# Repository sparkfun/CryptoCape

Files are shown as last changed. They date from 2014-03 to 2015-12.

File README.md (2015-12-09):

CryptoCape
==========

CryptoCape

[*CryptoCape (DEV-12773)*](https://www.sparkfun.com/products/12773)

A Cryptography Cape for the BeagleBone Black.

Repository Contents
-------------------

* **/Documentation** - PDF print of the board.
* **/Hardware** - All Eagle design files (.brd, .sch)
* **/Production** - Test bed files and production panel files

Documentation
--------------
* **[Hookup Guide](https://learn.sparkfun.com/tutorials/cryptocape-hookup-guide)** - Basic hookup guide for the CryptoCape.
* **[SparkFun Fritzing repo](https://github.com/sparkfun/Fritzing_Parts)** - Fritzing diagrams for SparkFun products.
* **[SparkFun 3D Model repo](https://github.com/sparkfun/3D_Models)** - 3D models of SparkFun products. 

License Information
-------------------

This product is _**open source**_! 

The hardware is released under [Creative Commons Share-alike 3.0](http://creativecommons.org/licenses/by-sa/3.0/).

If you have any questions or concerns on licensing, please contact techsupport@sparkfun.com.

Distributed as-is; no warranty is given.

- Your friends at SparkFun.

_This board is a collaboration with Josh Datko at Cryptotronix._

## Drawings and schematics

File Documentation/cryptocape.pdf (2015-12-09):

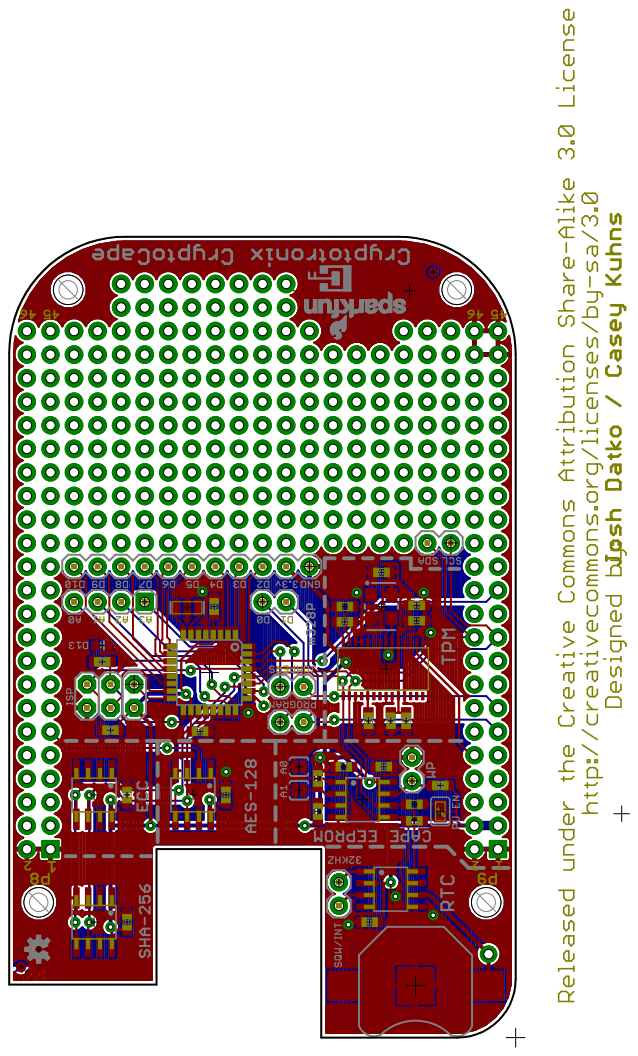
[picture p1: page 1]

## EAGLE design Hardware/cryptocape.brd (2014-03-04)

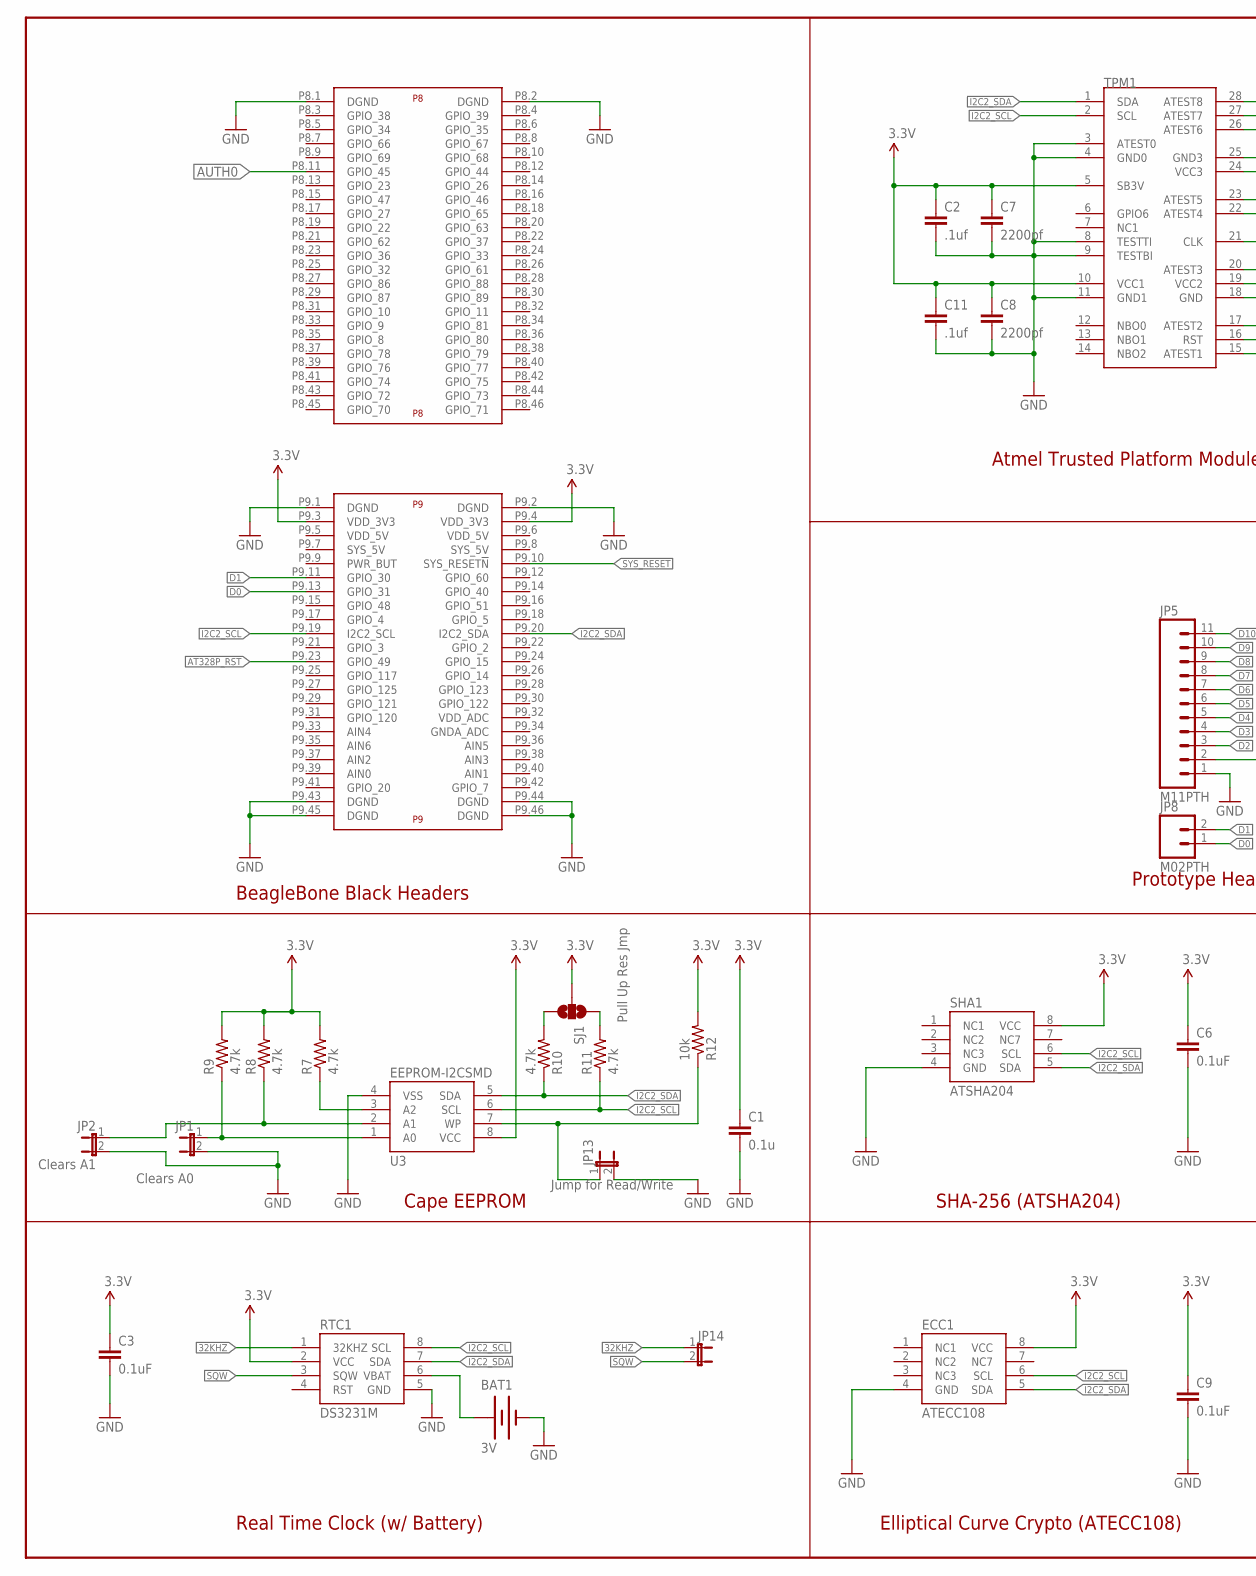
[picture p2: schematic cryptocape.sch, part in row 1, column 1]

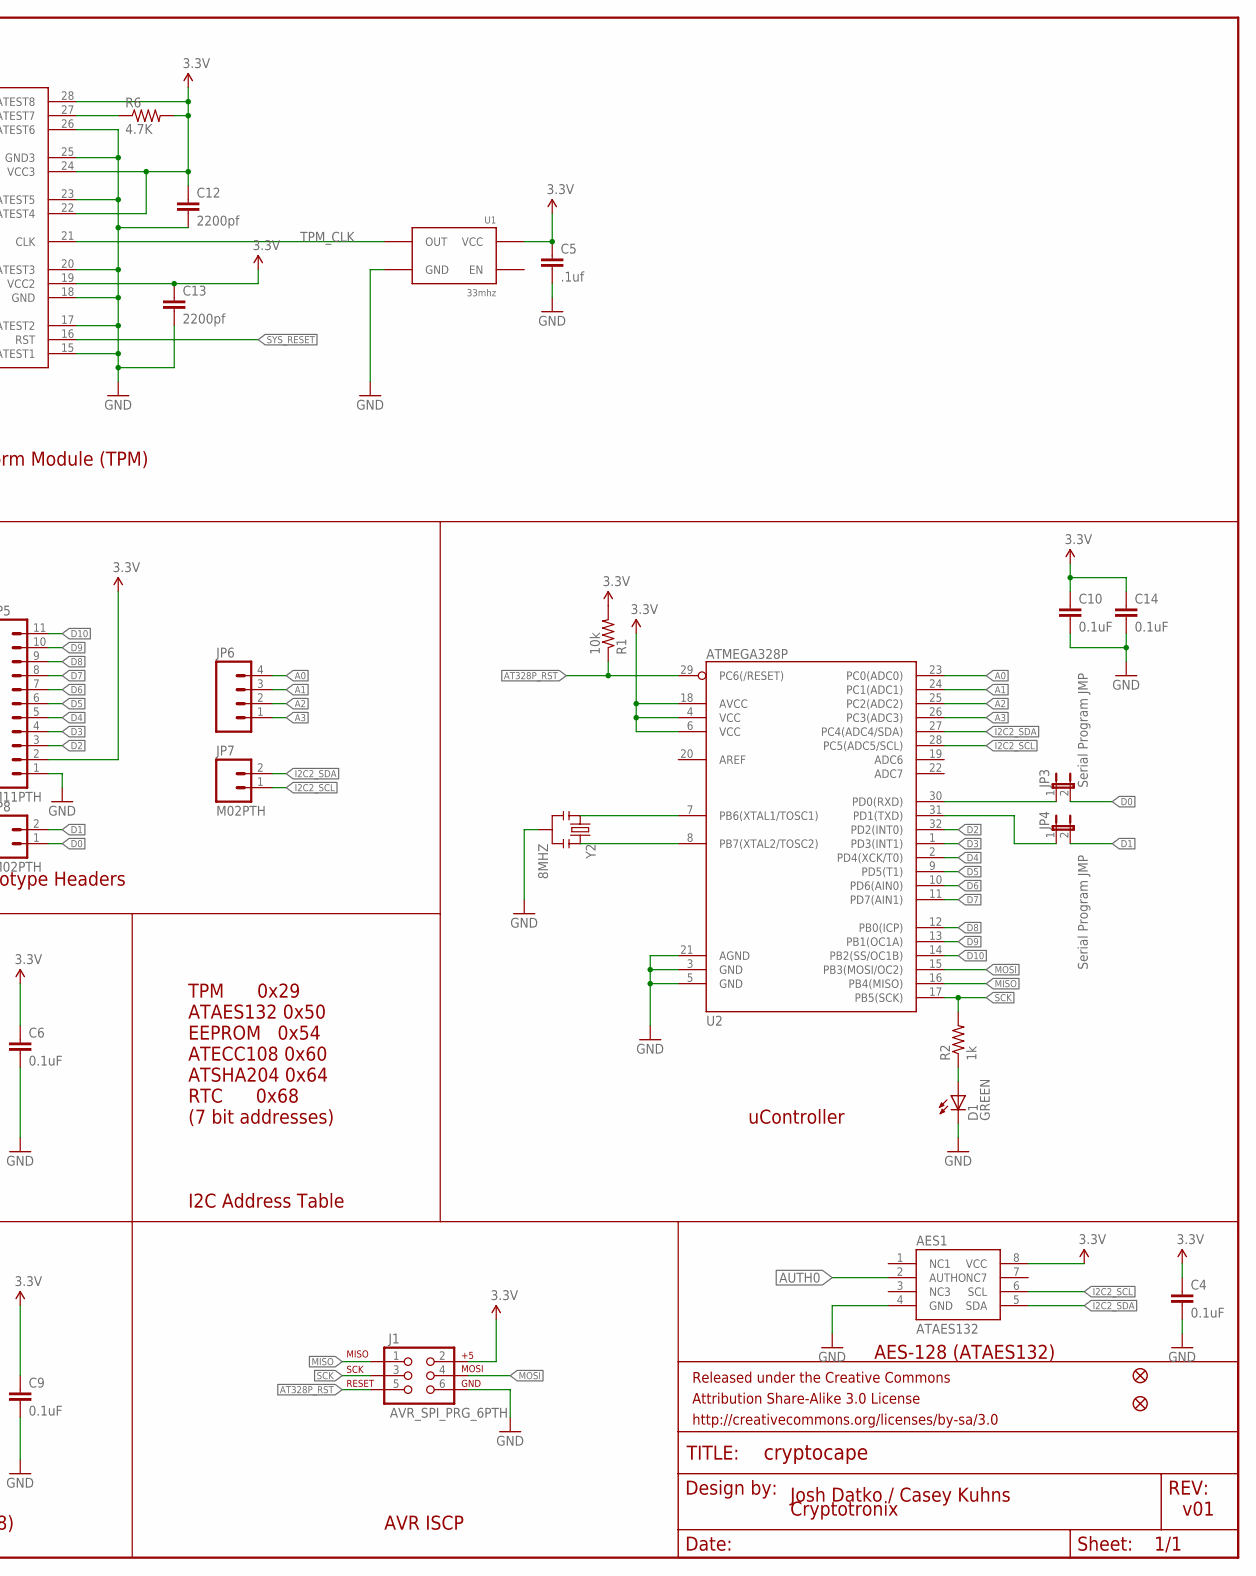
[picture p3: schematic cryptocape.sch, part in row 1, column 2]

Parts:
AES1: ATAES132; SOIC8
BAT1: 3V; BATTCON_12MM
C1: 0.1u; 0603-CAP
C2, C5, C11: .1uf; 0603-CAP
C3, C4, C6, C9, C10, C14: 0.1uF; 0603-CAP
C7, C8, C12, C13: 2200pf; 0603-CAP
D1: GREEN; LED-0603
ECC1: ATECC108; SOIC8
FID1, FID2: FIDUCIAL1X2; FIDUCIAL-1X2
FRAME1: FRAME-LEDGER; CREATIVE_COMMONS
J1: AVR_SPI_PRG_6PTH; 2X3
JP1: Clears A0; SJ_2S-NO
JP2: Clears A1; SJ_2S-NO
JP3, JP4: Serial Program JMP; 1X02
JP5: M11PTH; 1X11
JP6: M04PTH; 1X04
JP7, JP8: M02PTH; 1X02
JP13: Jump for Read/Write; 1X02
JP14: JUMPER-2PTH; 1X02
R1, R12: 10k; 0603-RES
R2: 1k; 0603-RES
R6: 4.7K; 0603
R7, R8, R9, R10, R11: 4.7k; 0603
RTC1: DS3231M; SOIC8
SHA1: ATSHA204; SOIC8
SJ1: Pull Up Res Jmp; SJ_3_PASTE1&2&3
TPM1: AT97SC3204T; TSSOP28
U1: 33mhz; CRYSTAL-OSC-SMD-5X3.2
U2: ATMEGA328P; TQFP32-08
U3: EEPROM-I2CSMD; SO08
U$2: BEAGLE_BONE_BLACK_CAPE
Y2: 8MHZ; RESONATOR-SMD

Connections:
3.3V: AES1.8 (VCC), C1.1, C2.1, C3.1, C4.1, C5.1, C6.1, C7.1, C8.1, C9.1, C10.1, C11.1, C12.1, C13.1, C14.1, ECC1.8 (VCC), J1.2, JP5.2, R1.2, R6.2, R7.2, R8.2, R9.2, R12.2, RTC1.2 (VCC), SHA1.8 (VCC), SJ1.2, TPM1.5 (SB3V), TPM1.10 (VCC1), TPM1.19 (VCC2), TPM1.22 (ATEST4), TPM1.24 (VCC3), TPM1.28 (ATEST8), U1.4 (VCC), U2.4 (VCC), U2.6 (VCC), U2.18 (AVCC), U3.8 (VCC), U$2.P9.3 (VDD_3V3), U$2.P9.4 (VDD_3V3)
32KHZ: JP14.1, RTC1.1 (32KHZ)
A0: JP6.4, U2.23 (PC0(ADC0))
A1: JP6.3, U2.24 (PC1(ADC1))
A2: JP6.2, U2.25 (PC2(ADC2))
A3: JP6.1, U2.26 (PC3(ADC3))
AT328P_RST: J1.5, R1.1, U2.29 (PC6(/RESET)), U$2.P9.23 (GPIO_49)
AUTH0: AES1.2 (AUTHO), U$2.P8.11 (GPIO_45)
D0: JP3.2, JP8.1, U$2.P9.13 (GPIO_31)
D0': JP3.1, U2.30 (PD0(RXD))
D1: JP4.2, JP8.2, U$2.P9.11 (GPIO_30)
D1': JP4.1, U2.31 (PD1(TXD))
D2: JP5.3, U2.32 (PD2(INT0))
D3: JP5.4, U2.1 (PD3(INT1))
D4: JP5.5, U2.2 (PD4(XCK/T0))
D5: JP5.6, U2.9 (PD5(T1))
D6: JP5.7, U2.10 (PD6(AIN0))
D7: JP5.8, U2.11 (PD7(AIN1))
D8: JP5.9, U2.12 (PB0(ICP))
D9: JP5.10, U2.13 (PB1(OC1A))
D10: JP5.11, U2.14 (PB2(SS/OC1B))
GND: AES1.4 (GND), BAT1.GND (-), C1.2, C2.2, C3.2, C4.2, C5.2, C6.2, C7.2, C8.2, C9.2, C10.2, C11.2, C12.2, C13.2, C14.2, D1.C, ECC1.4 (GND), J1.6, JP1.2, JP2.2, JP5.1, JP13.2, RTC1.5 (GND), SHA1.4 (GND), TPM1.3 (ATEST0), TPM1.4 (GND0), TPM1.8 (TESTTI), TPM1.9 (TESTBI), TPM1.11 (GND1), TPM1.15 (ATEST1), TPM1.17 (ATEST2), TPM1.18 (GND), TPM1.20 (ATEST3), TPM1.23 (ATEST5), TPM1.25 (GND3), TPM1.26 (ATEST6), U1.2 (GND), U2.3 (GND), U2.5 (GND), U2.21 (AGND), U3.4 (VSS), U$2.P8.1 (DGND), U$2.P8.2 (DGND), U$2.P9.1 (DGND), U$2.P9.2 (DGND), U$2.P9.43 (DGND), U$2.P9.44 (DGND), U$2.P9.45 (DGND), U$2.P9.46 (DGND), Y2.2
I2C2_SCL: AES1.6 (SCL), ECC1.6 (SCL), JP7.1, R11.1, RTC1.8 (SCL), SHA1.6 (SCL), TPM1.2 (SCL), U2.28 (PC5(ADC5/SCL)), U3.6 (SCL), U$2.P9.19 (I2C2_SCL)
I2C2_SDA: AES1.5 (SDA), ECC1.5 (SDA), JP7.2, R10.1, RTC1.7 (SDA), SHA1.5 (SDA), TPM1.1 (SDA), U2.27 (PC4(ADC4/SDA)), U3.5 (SDA), U$2.P9.20 (I2C2_SDA)
MISO: J1.1, U2.16 (PB4(MISO))
MOSI: J1.4, U2.15 (PB3(MOSI/OC2))
unnamed: JP13.1, R12.1, U3.7 (WP)
unnamed: U2.7 (PB6(XTAL1/TOSC1)), Y2.1
unnamed: U2.8 (PB7(XTAL2/TOSC2)), Y2.3
unnamed: D1.A, R2.1
unnamed: R7.1, U3.3 (A2)
unnamed: R6.1, TPM1.27 (ATEST7)
unnamed: JP2.1, R8.1, U3.2 (A1)
unnamed: JP1.1, R9.1, U3.1 (A0)
unnamed: R10.2, SJ1.3
unnamed: R11.2, SJ1.1
SCK: J1.3, R2.2, U2.17 (PB5(SCK))
SQW: JP14.2, RTC1.3 (SQW)
SYS_RESET: TPM1.16 (RST), U$2.P9.10 (SYS_RESET!N)
TPM_CLK: TPM1.21 (CLK), U1.3 (OUT)
VBAT: BAT1.PWR@1 (+), RTC1.6 (VBAT)

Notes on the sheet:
Cryptotronix
BeagleBone Black Headers
Cape EEPROM
Real Time Clock (w/ Battery)
Atmel Trusted Platform Module (TPM)
Elliptical Curve Crypto (ATECC108)
AVR ISCP
uController
SHA-256 (ATSHA204)
Prototype Headers
I2C Address Table
TPM 0x29 ATAES132 0x50 EEPROM 0x54 ATECC108 0x60 ATSHA204 0x64 RTC 0x68 (7 bit addresses)
AES-128 (ATAES132)
Josh Datko / Casey Kuhns
v01

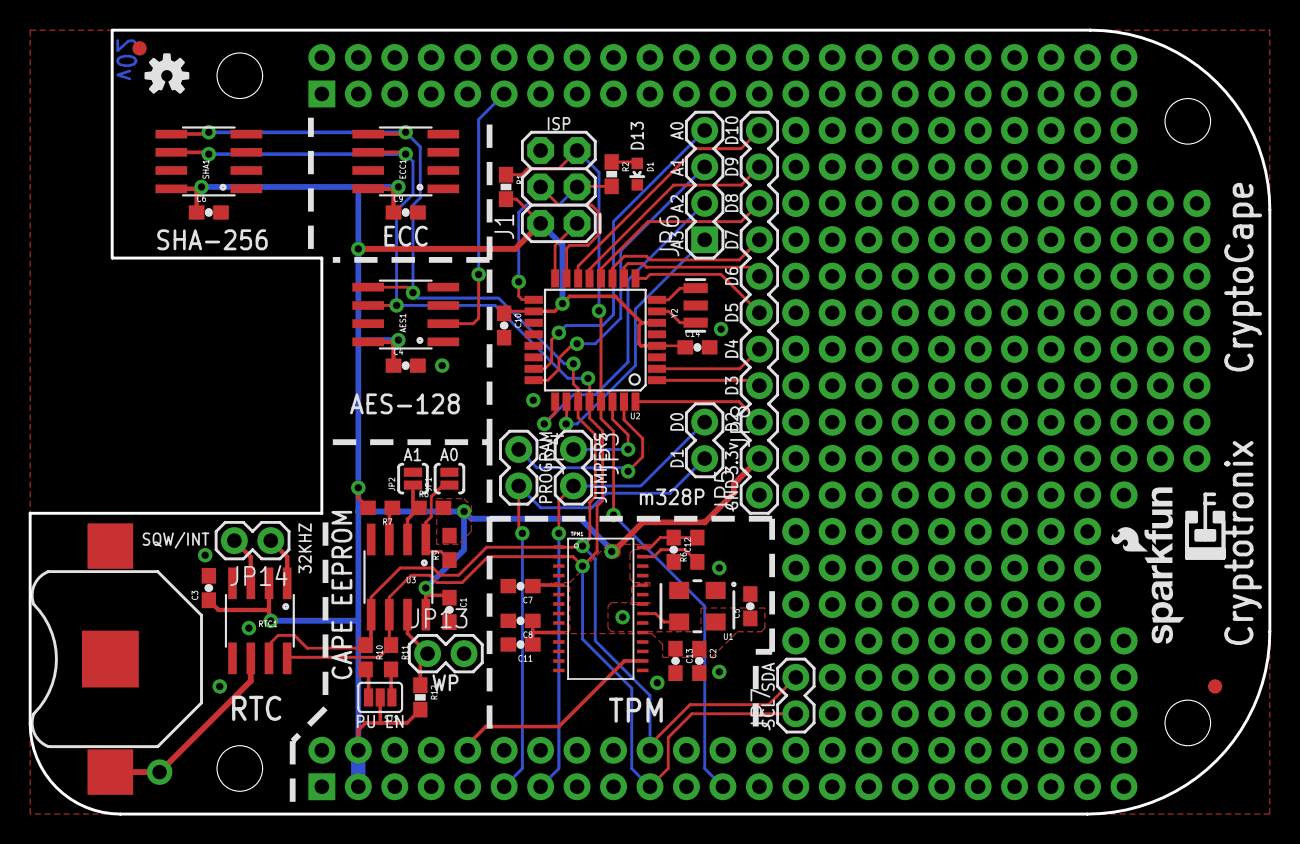
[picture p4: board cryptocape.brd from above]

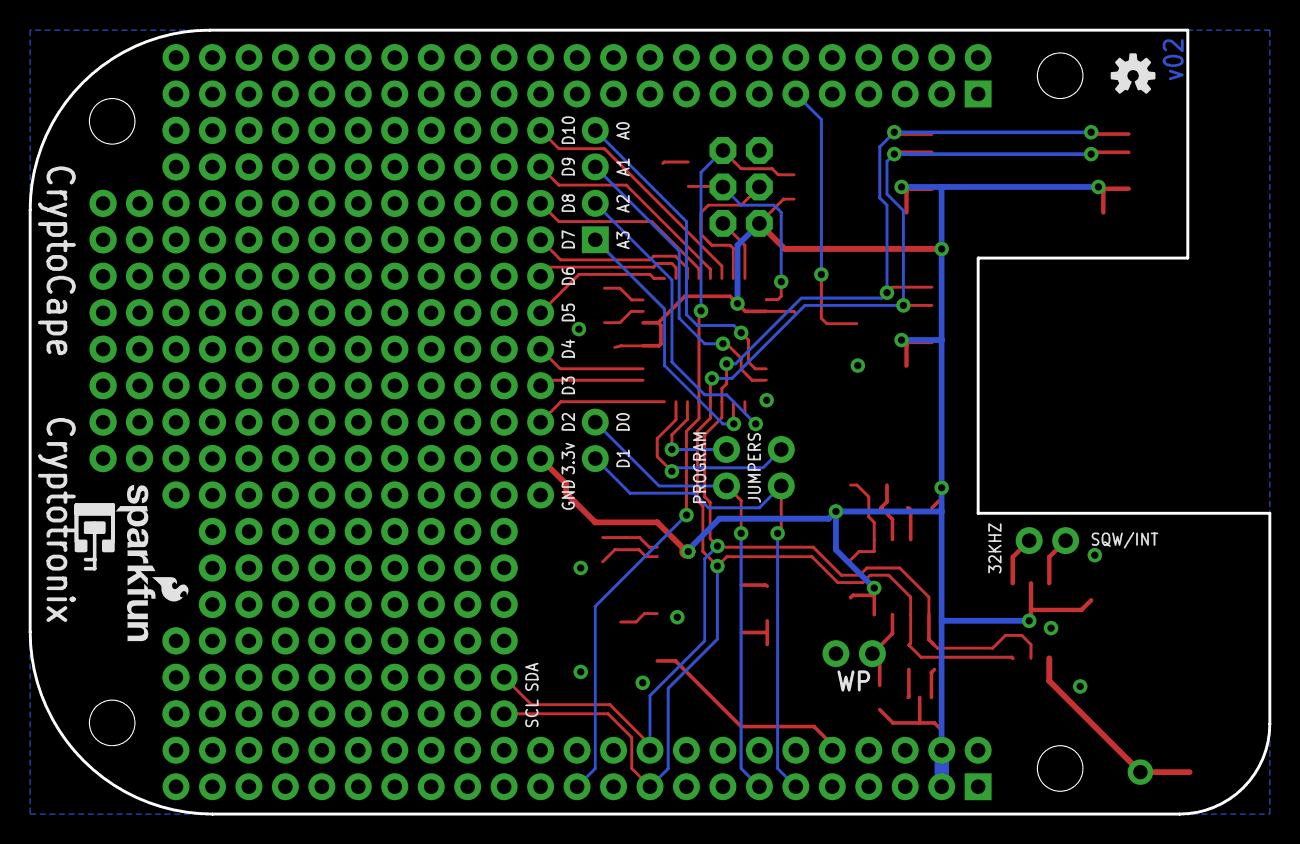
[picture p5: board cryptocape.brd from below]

Board: 2 copper layers, 86.4 x 54.6 mm, 54 parts (2 on the bottom side), 41 nets.

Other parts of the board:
U$3, U$6: OSHW-LOGO-S
U$4, U$5: SFE_LOGO_NAME_FLAME_.1

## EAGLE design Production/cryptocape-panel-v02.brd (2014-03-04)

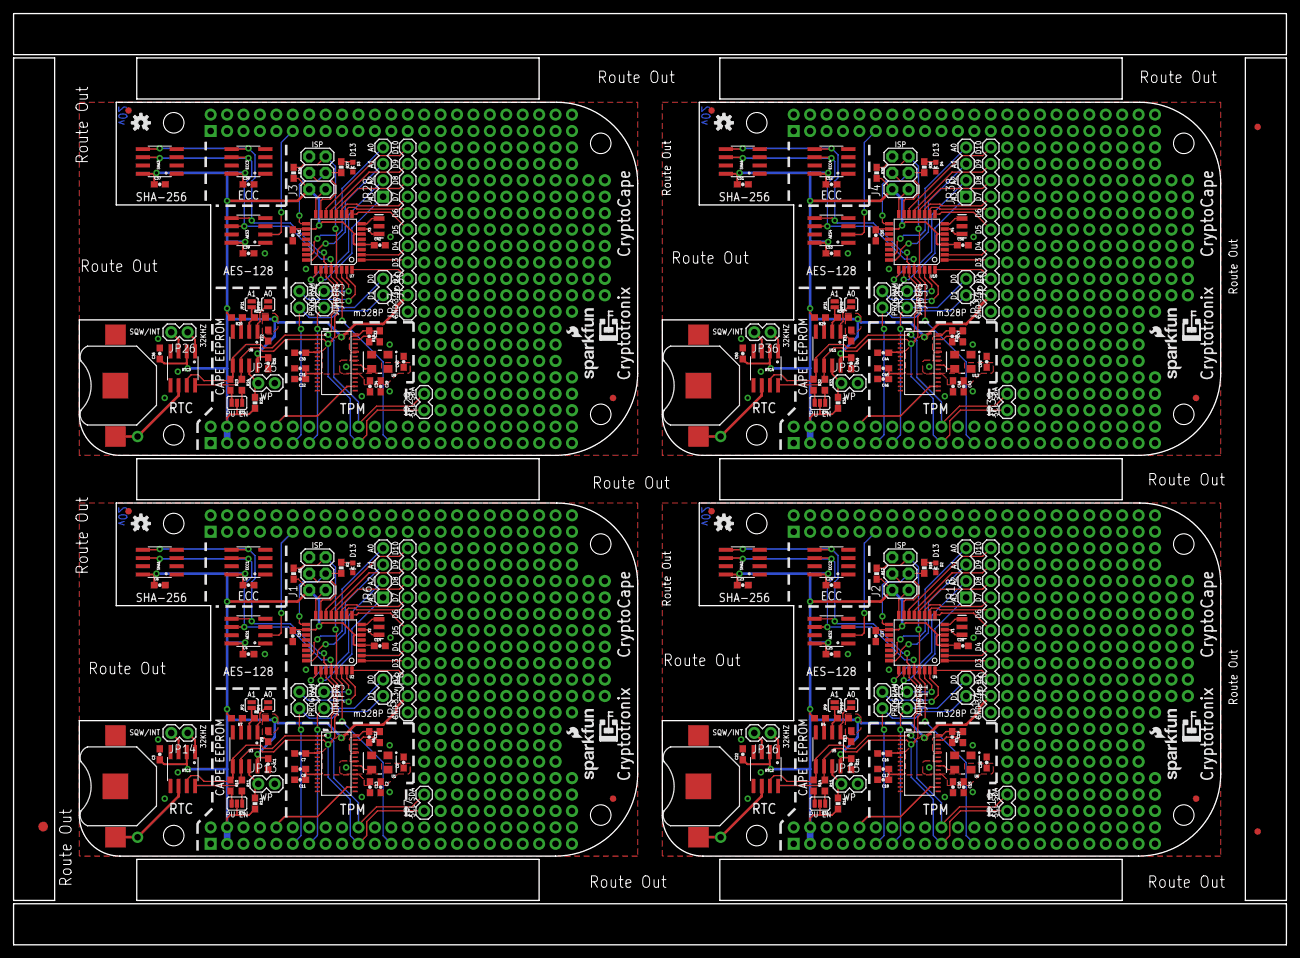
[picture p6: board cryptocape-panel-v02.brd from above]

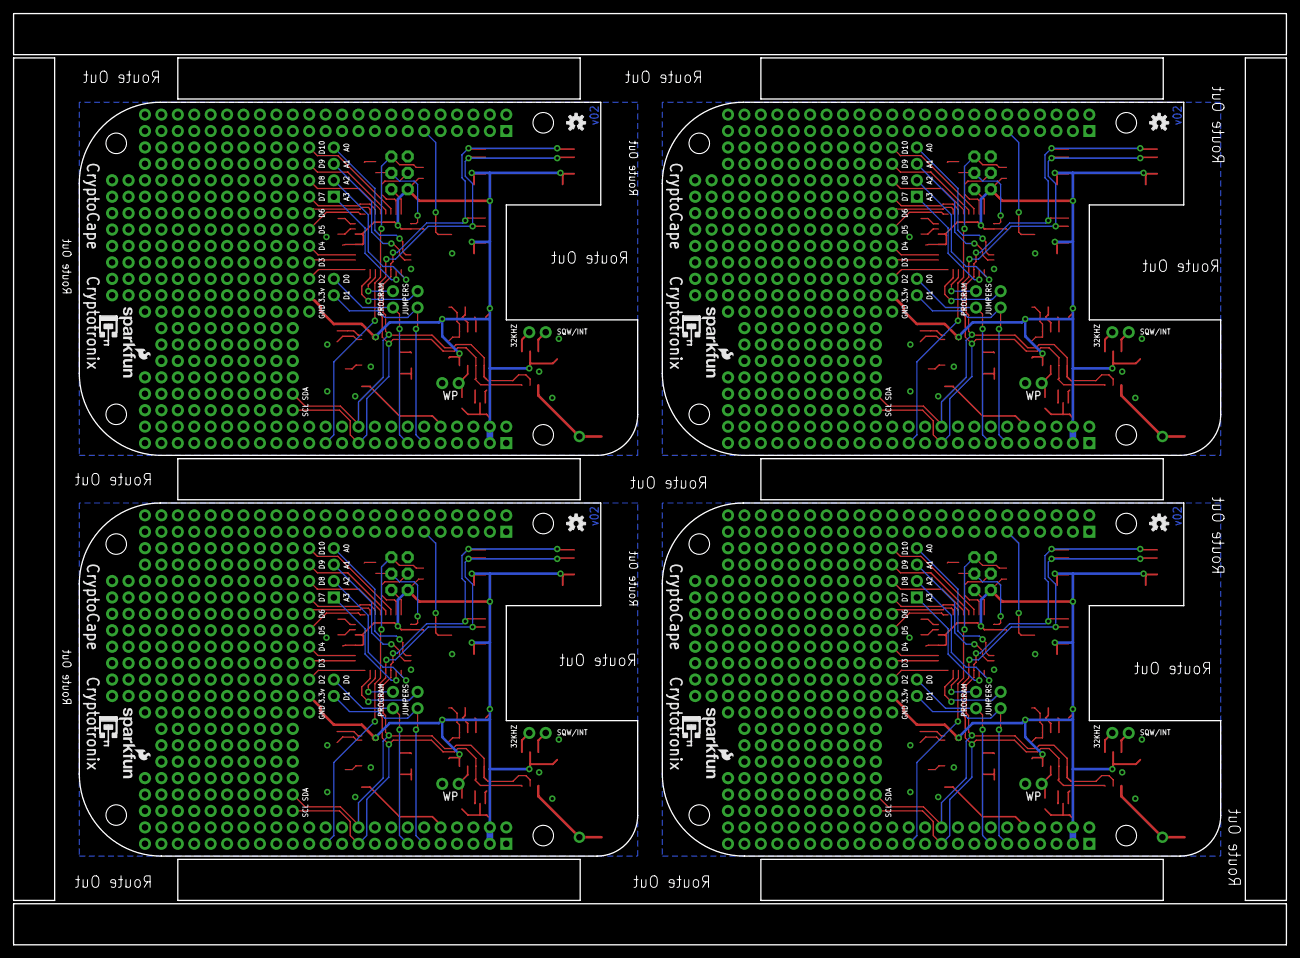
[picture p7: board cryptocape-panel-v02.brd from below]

Board: 2 copper layers, 196.8 x 144.0 mm, 215 parts (8 on the bottom side), 164 nets.

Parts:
AES1, AES2, AES3, AES4: ATAES132; SOIC8
BAT1, BAT2, BAT3, BAT4: 3V; BATTCON_12MM
C1, C21, C35, C49: 0.1u; 0603-CAP
C2, C5, C11, C15, C18, C26, C29, C32, C40, C43, C46, C54: .1uf; 0603-CAP
C3, C4, C6, C9, C10, C14, C22, C23, C24, C25, C27, C28, C36, C37, C38, C39, C41, C42, C50, C51, C52, C53, C55, C56: 0.1uF; 0603-CAP
C7, C8, C12, C13, C16, C17, C19, C20, C30, C31, C33, C34, C44, C45, C47, C48: 2200pf; 0603-CAP
D1, D2, D3, D4: GREEN; LED-0603
E$1: FIDUCIAL-1.5X3
E$12, E$14: FIDUCIAL-1X2
ECC1, ECC2, ECC3, ECC4: ATECC108; SOIC8
FID1, FID2, FID3, FID4, FID5, FID6, FID7, FID8: FIDUCIAL1X2; FIDUCIAL-1X2
J1, J2, J3, J4: AVR_SPI_PRG_6PTH; 2X3
JP1, JP10, JP22, JP32: Clears A0; SJ_2S-NO
JP2, JP9, JP21, JP31: Clears A1; SJ_2S-NO
JP3, JP4, JP11, JP12, JP23, JP24, JP33, JP34: Serial Program JMP; 1X02
JP5, JP17, JP27, JP37: M11PTH; 1X11
JP6, JP18, JP28, JP38: 1X04
JP7, JP8, JP19, JP20, JP29, JP30, JP39, JP40: M02PTH; 1X02
JP13, JP15, JP25, JP35: Jump for Read/Write; 1X02
JP14, JP16, JP26, JP36: 1X02
R1, R12, R16, R17, R25, R26, R34, R35: 10k; 0603-RES
R2, R18, R27, R36: 1k; 0603-RES
R3, R6, R19, R28: 4.7K; 0603
R4, R5, R7, R8, R9, R10, R11, R13, R14, R15, R20, R21, R22, R23, R24, R29, R30, R31, R32, R33: 4.7k; 0603
RTC1, RTC2, RTC3, RTC4: DS3231M; SOIC8
SHA1, SHA2, SHA3, SHA4: ATSHA204; SOIC8
SJ1, SJ2, SJ3, SJ4: Pull Up Res Jmp; SJ_3_PASTE1&2&3
TPM1, TPM2, TPM3, TPM4: AT97SC3204T; TSSOP28
U1, U6, U9, U12: 33mhz; CRYSTAL-OSC-SMD-5X3.2
U2, U4, U7, U10: ATMEGA328P; TQFP32-08
U3, U5, U8, U11: EEPROM-I2CSMD; SO08
U$1, U$2, U$11, U$16: BEAGLE_BONE_BLACK_CAPE
U$3, U$6, U$7, U$10, U$12, U$15, U$17, U$20: OSHW-LOGO-S
U$4, U$5, U$8, U$9, U$13, U$14, U$18, U$19: SFE_LOGO_NAME_FLAME_.1
Y1, Y2, Y3, Y4: 8MHZ; RESONATOR-SMD

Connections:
3.3V: AES1.8, C1.1, C2.1, C3.1, C4.1, C5.1, C6.1, C7.1, C8.1, C9.1, C10.1, C11.1, C12.1, C13.1, C14.1, ECC1.8, J1.2, JP5.2, R1.2, R6.2, R7.2, R8.2, R9.2, R12.2, RTC1.2, SHA1.8, SJ1.2, TPM1.5, TPM1.10, TPM1.19, TPM1.22, TPM1.24, TPM1.28, U1.4, U2.4, U2.6, U2.18, U3.8, U$2.P9.3, U$2.P9.4
3.3V1: AES2.8, C15.1, C16.1, C17.1, C18.1, C19.1, C20.1, C21.1, C22.1, C23.1, C24.1, C25.1, C26.1, C27.1, C28.1, ECC2.8, J2.2, JP17.2, R3.2, R4.2, R5.2, R13.2, R16.2, R17.2, RTC2.2, SHA2.8, SJ2.2, TPM2.5, TPM2.10, TPM2.19, TPM2.22, TPM2.24, TPM2.28, U4.4, U4.6, U4.18, U5.8, U6.4, U$1.P9.3, U$1.P9.4
3.3V2: AES3.8, C29.1, C30.1, C31.1, C32.1, C33.1, C34.1, C35.1, C36.1, C37.1, C38.1, C39.1, C40.1, C41.1, C42.1, ECC3.8, J3.2, JP27.2, R19.2, R20.2, R21.2, R22.2, R25.2, R26.2, RTC3.2, SHA3.8, SJ3.2, TPM3.5, TPM3.10, TPM3.19, TPM3.22, TPM3.24, TPM3.28, U7.4, U7.6, U7.18, U8.8, U9.4, U$11.P9.3, U$11.P9.4
3.3V3: AES4.8, C43.1, C44.1, C45.1, C46.1, C47.1, C48.1, C49.1, C50.1, C51.1, C52.1, C53.1, C54.1, C55.1, C56.1, ECC4.8, J4.2, JP37.2, R28.2, R29.2, R30.2, R31.2, R34.2, R35.2, RTC4.2, SHA4.8, SJ4.2, TPM4.5, TPM4.10, TPM4.19, TPM4.22, TPM4.24, TPM4.28, U10.4, U10.6, U10.18, U11.8, U12.4, U$16.P9.3, U$16.P9.4
32KHZ: JP14.1, RTC1.1
32KHZ1: JP16.1, RTC2.1
32KHZ2: JP26.1, RTC3.1
32KHZ3: JP36.1, RTC4.1
A0: JP6.4, U2.23
A1: JP6.3, U2.24
A2: JP6.2, U2.25
A3: JP6.1, U2.26
A4: JP18.3, U4.24
A5: JP18.2, U4.25
A6: JP18.1, U4.26
A7: JP18.4, U4.23
A8: JP28.3, U7.24
A9: JP28.2, U7.25
A10: JP28.1, U7.26
A11: JP28.4, U7.23
A12: JP38.3, U10.24
A13: JP38.2, U10.25
A14: JP38.1, U10.26
A15: JP38.4, U10.23
AT328P_RST: J1.5, R1.1, U2.29, U$2.P9.23
AT328P_RST1: J2.5, R17.1, U4.29, U$1.P9.23
AT328P_RST2: J3.5, R26.1, U7.29, U$11.P9.23
AT328P_RST3: J4.5, R35.1, U10.29, U$16.P9.23
AUTH0: AES1.2, U$2.P8.11
AUTH1: AES2.2, U$1.P8.11
AUTH2: AES3.2, U$11.P8.11
AUTH3: AES4.2, U$16.P8.11
D0: JP3.2, JP8.1, U$2.P9.13
D0': JP3.1, U2.30
D0'1: JP11.1, U4.30
D0'2: JP23.1, U7.30
D0'3: JP33.1, U10.30
D1: JP4.2, JP8.2, U$2.P9.11
D1': JP4.1, U2.31
D1'1: JP12.1, U4.31
D1'2: JP24.1, U7.31
D1'3: JP34.1, U10.31
D2: JP5.3, U2.32
D3: JP5.4, U2.1
D4: JP5.5, U2.2
D5: JP5.6, U2.9
D6: JP5.7, U2.10
D7: JP5.8, U2.11
D8: JP5.9, U2.12
D9: JP5.10, U2.13
D10: JP5.11, U2.14
D11: JP11.2, JP20.1, U$1.P9.13
D12: JP12.2, JP20.2, U$1.P9.11
D13: JP17.3, U4.32
D14: JP17.4, U4.1
D15: JP17.5, U4.2
D16: JP17.6, U4.9
D17: JP17.7, U4.10
D18: JP17.8, U4.11
D19: JP17.9, U4.12
D20: JP17.10, U4.13
D21: JP17.11, U4.14
D22: JP23.2, JP30.1, U$11.P9.13
D23: JP24.2, JP30.2, U$11.P9.11
D24: JP27.3, U7.32
D25: JP27.4, U7.1
D26: JP27.5, U7.2
D27: JP27.6, U7.9
D28: JP27.7, U7.10
D29: JP27.8, U7.11
D30: JP27.9, U7.12
D31: JP27.10, U7.13
D32: JP27.11, U7.14
D33: JP33.2, JP40.1, U$16.P9.13
D34: JP34.2, JP40.2, U$16.P9.11
D35: JP37.3, U10.32
D36: JP37.4, U10.1
D37: JP37.5, U10.2
D38: JP37.6, U10.9
D39: JP37.7, U10.10
D40: JP37.8, U10.11
D41: JP37.9, U10.12
D42: JP37.10, U10.13
D43: JP37.11, U10.14
GND: AES1.4, BAT1.GND, C1.2, C2.2, C3.2, C4.2, C5.2, C6.2, C7.2, C8.2, C9.2, C10.2, C11.2, C12.2, C13.2, C14.2, D1.C, ECC1.4, J1.6, JP1.2, JP2.2, JP5.1, JP13.2, RTC1.5, SHA1.4, TPM1.3, TPM1.4, TPM1.8, TPM1.9, TPM1.11, TPM1.15, TPM1.17, TPM1.18, TPM1.20, TPM1.23, TPM1.25, TPM1.26, U1.2, U2.3, U2.5, U2.21, U3.4, U$2.P8.1, U$2.P8.2, U$2.P9.1, U$2.P9.2, U$2.P9.43, U$2.P9.44, U$2.P9.45, U$2.P9.46, Y2.2
GND1: AES2.4, BAT2.GND, C15.2, C16.2, C17.2, C18.2, C19.2, C20.2, C21.2, C22.2, C23.2, C24.2, C25.2, C26.2, C27.2, C28.2, D2.C, ECC2.4, J2.6, JP9.2, JP10.2, JP15.2, JP17.1, RTC2.5, SHA2.4, TPM2.3, TPM2.4, TPM2.8, TPM2.9, TPM2.11, TPM2.15, TPM2.17, TPM2.18, TPM2.20, TPM2.23, TPM2.25, TPM2.26, U4.3, U4.5, U4.21, U5.4, U6.2, U$1.P8.1, U$1.P8.2, U$1.P9.1, U$1.P9.2, U$1.P9.43, U$1.P9.44, U$1.P9.45, U$1.P9.46, Y1.2
GND2: AES3.4, BAT3.GND, C29.2, C30.2, C31.2, C32.2, C33.2, C34.2, C35.2, C36.2, C37.2, C38.2, C39.2, C40.2, C41.2, C42.2, D3.C, ECC3.4, J3.6, JP21.2, JP22.2, JP25.2, JP27.1, RTC3.5, SHA3.4, TPM3.3, TPM3.4, TPM3.8, TPM3.9, TPM3.11, TPM3.15, TPM3.17, TPM3.18, TPM3.20, TPM3.23, TPM3.25, TPM3.26, U7.3, U7.5, U7.21, U8.4, U9.2, U$11.P8.1, U$11.P8.2, U$11.P9.1, U$11.P9.2, U$11.P9.43, U$11.P9.44, U$11.P9.45, U$11.P9.46, Y3.2
GND3: AES4.4, BAT4.GND, C43.2, C44.2, C45.2, C46.2, C47.2, C48.2, C49.2, C50.2, C51.2, C52.2, C53.2, C54.2, C55.2, C56.2, D4.C, ECC4.4, J4.6, JP31.2, JP32.2, JP35.2, JP37.1, RTC4.5, SHA4.4, TPM4.3, TPM4.4, TPM4.8, TPM4.9, TPM4.11, TPM4.15, TPM4.17, TPM4.18, TPM4.20, TPM4.23, TPM4.25, TPM4.26, U10.3, U10.5, U10.21, U11.4, U12.2, U$16.P8.1, U$16.P8.2, U$16.P9.1, U$16.P9.2, U$16.P9.43, U$16.P9.44, U$16.P9.45, U$16.P9.46, Y4.2
I2C2_SCL: AES1.6, ECC1.6, JP7.1, R11.1, RTC1.8, SHA1.6, TPM1.2, U2.28, U3.6, U$2.P9.19
I2C2_SCL1: AES2.6, ECC2.6, JP19.1, R15.1, RTC2.8, SHA2.6, TPM2.2, U4.28, U5.6, U$1.P9.19
I2C2_SCL2: AES3.6, ECC3.6, JP29.1, R24.1, RTC3.8, SHA3.6, TPM3.2, U7.28, U8.6, U$11.P9.19
I2C2_SCL3: AES4.6, ECC4.6, JP39.1, R33.1, RTC4.8, SHA4.6, TPM4.2, U10.28, U11.6, U$16.P9.19
I2C2_SDA: AES1.5, ECC1.5, JP7.2, R10.1, RTC1.7, SHA1.5, TPM1.1, U2.27, U3.5, U$2.P9.20
I2C2_SDA1: AES2.5, ECC2.5, JP19.2, R14.1, RTC2.7, SHA2.5, TPM2.1, U4.27, U5.5, U$1.P9.20
I2C2_SDA2: AES3.5, ECC3.5, JP29.2, R23.1, RTC3.7, SHA3.5, TPM3.1, U7.27, U8.5, U$11.P9.20
I2C2_SDA3: AES4.5, ECC4.5, JP39.2, R32.1, RTC4.7, SHA4.5, TPM4.1, U10.27, U11.5, U$16.P9.20
MISO: J1.1, U2.16
MISO1: J2.1, U4.16
MISO2: J3.1, U7.16
MISO3: J4.1, U10.16
MOSI: J1.4, U2.15
MOSI1: J2.4, U4.15
MOSI2: J3.4, U7.15
MOSI3: J4.4, U10.15
unnamed: JP13.1, R12.1, U3.7
unnamed: U2.7, Y2.1
unnamed: U2.8, Y2.3
unnamed: D1.A, R2.1
unnamed: R7.1, U3.3
unnamed: R6.1, TPM1.27
unnamed: JP2.1, R8.1, U3.2
unnamed: JP1.1, R9.1, U3.1
unnamed: R10.2, SJ1.3
unnamed: R11.2, SJ1.1
unnamed: U4.7, Y1.1
unnamed: U4.8, Y1.3
unnamed: R3.1, TPM2.27
unnamed: R4.1, U5.3
unnamed: JP9.1, R5.1, U5.2
unnamed: JP10.1, R13.1, U5.1
unnamed: R14.2, SJ2.3
unnamed: R15.2, SJ2.1
unnamed: JP15.1, R16.1, U5.7
unnamed: D2.A, R18.1
unnamed: U7.7, Y3.1
unnamed: U7.8, Y3.3
unnamed: R19.1, TPM3.27
unnamed: R20.1, U8.3
unnamed: JP21.1, R21.1, U8.2
unnamed: JP22.1, R22.1, U8.1
unnamed: R23.2, SJ3.3
unnamed: R24.2, SJ3.1
unnamed: JP25.1, R25.1, U8.7
unnamed: D3.A, R27.1
unnamed: U10.7, Y4.1
unnamed: U10.8, Y4.3
unnamed: R28.1, TPM4.27
unnamed: R29.1, U11.3
unnamed: JP31.1, R30.1, U11.2
unnamed: JP32.1, R31.1, U11.1
unnamed: R32.2, SJ4.3
unnamed: R33.2, SJ4.1
unnamed: JP35.1, R34.1, U11.7
unnamed: D4.A, R36.1
SCK: J1.3, R2.2, U2.17
SCK1: J2.3, R18.2, U4.17
SCK2: J3.3, R27.2, U7.17
SCK3: J4.3, R36.2, U10.17
SQW: JP14.2, RTC1.3
SQW1: JP16.2, RTC2.3
SQW2: JP26.2, RTC3.3
SQW3: JP36.2, RTC4.3
SYS_RESET: TPM1.16, U$2.P9.10
SYS_RESET1: TPM2.16, U$1.P9.10
SYS_RESET2: TPM3.16, U$11.P9.10
SYS_RESET3: TPM4.16, U$16.P9.10
TPM_CLK: TPM1.21, U1.3
TPM_CLK1: TPM2.21, U6.3
TPM_CLK2: TPM3.21, U9.3
TPM_CLK3: TPM4.21, U12.3
VBAT: BAT1.PWR@1, RTC1.6
VBAT1: BAT2.PWR@1, RTC2.6
VBAT2: BAT3.PWR@1, RTC3.6
VBAT3: BAT4.PWR@1, RTC4.6

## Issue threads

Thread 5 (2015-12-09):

Please add PDF or other freely readible images of the board trace layouts

herrold, 2015-12-09:
The files currently offered require ownership and setup of a Eagle (proprietary) piece of software to effectively render a view.  Please add PDF or other graphical image forms not requiring such

(this issue arose doing IRC support)

ToniCorinne, 2015-12-09:
I've added a PDF to the repo. Thanks for doing IRC support!

A note for anyone that comes across this- there is a [Freeware version](http://www.cadsoftusa.com/download-eagle/freeware/) of Eagle available to allow users to open and view all of our design files.

jbdatko, 2015-12-09:
Thanks @ToniCorinne !

Closed 2015-12-09.

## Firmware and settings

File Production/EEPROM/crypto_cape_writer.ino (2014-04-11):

// Program to write in the EERPROM on the CryptoCape

#include <Wire.h>
#include <avr/pgmspace.h>

byte eeprom_addr = 0x57;
unsigned long crc = 0;
unsigned long crc_check = 0;
int led = 13;

static uint8_t eeprom_data[] = 
{
    0xaa, 0x55, 0x33, 0xee, 0x41, 0x31, 0x42, 0x42, 0x2d, 0x42, 0x4f,
    0x4e, 0x45, 0x2d, 0x43, 0x52, 0x59, 0x50, 0x54, 0x4f, 0x00, 0x00,
    0x00, 0x00, 0x00, 0x00, 0x00, 0x00, 0x00, 0x00, 0x00, 0x00, 0x00,
    0x00, 0x00, 0x00, 0x00, 0x00, 0x30, 0x30, 0x41, 0x30, 0x53, 0x70,
    0x61, 0x72, 0x6b, 0x46, 0x75, 0x6e, 0x00, 0x00, 0x00, 0x00, 0x00,
    0x00, 0x00, 0x00, 0x42, 0x42, 0x2d, 0x42, 0x4f, 0x4e, 0x45, 0x2d,
    0x43, 0x52, 0x59, 0x50, 0x54, 0x4f, 0x00, 0x00, 0x00, 0x11, 0x32,
    0x30, 0x31, 0x34, 0x30, 0x30, 0x30, 0x30, 0x30, 0x30, 0x30, 0x30,
    0x00, 0x00, 0x00, 0x00, 0x00, 0x00, 0x00, 0x00, 0x00, 0x00, 0x00,
    0x00, 0x00, 0x00, 0x00, 0x00, 0x00, 0x00, 0xe0, 0x73, 0xe0, 0x73,
    0x00, 0x00, 0x00, 0x00, 0x00, 0x00, 0x00, 0x00, 0x00, 0x00, 0x00,
    0x00, 0x00, 0x00, 0xa0, 0x26, 0xc0, 0x06, 0x00, 0x00, 0x00, 0x00,
    0x00, 0x00, 0x00, 0x00, 0x00, 0x00, 0x00, 0x00, 0x00, 0x00, 0x00,
    0x00, 0x00, 0x00, 0xa0, 0x2f, 0x00, 0x00, 0x00, 0x00, 0x00, 0x00,
    0xc0, 0x17, 0x00, 0x00, 0x00, 0x00, 0x00, 0x00, 0x00, 0x00, 0x00,
    0x00, 0x00, 0x00, 0x00, 0x00, 0x00, 0x00, 0x00, 0x00, 0x00, 0x00,
    0x00, 0x00, 0x00, 0x00, 0x00, 0x00, 0x00, 0x00, 0x00, 0x00, 0x00,
    0x00, 0x00, 0x00, 0x00, 0x00, 0x00, 0x00, 0x00, 0x00, 0x00, 0x00,
    0x00, 0x00, 0x00, 0x00, 0x00, 0x00, 0x00, 0x00, 0x00, 0x00, 0x00,
    0x00, 0x00, 0x00, 0x00, 0x00, 0x00, 0x00, 0x00, 0x00, 0x00, 0x00,
    0x00, 0x00, 0x00, 0x00, 0x00, 0x00, 0x00, 0x00, 0x00, 0x00, 0x00,
    0x00, 0x00, 0x00, 0x00, 0x00, 0x01, 0xf4, 0x00, 0x00, 0x00, 0x00,
    0x00, 0x00, 0x47, 0x50, 0x47, 0x20, 0x46, 0x69, 0x6e, 0x67, 0x65,
    0x72, 0x70, 0x72, 0x69, 0x6e, 0x74, 0x3a, 0x20, 0x30, 0x78, 0x42,
    0x35, 0x39, 0x31, 0x39, 0x42, 0x31, 0x41, 0x43, 0x37, 0x31, 0x33,
    0x35, 0x39, 0x30, 0x35, 0x46, 0x34, 0x36, 0x36, 0x39, 0x43, 0x38,
    0x34, 0x37, 0x42, 0x46, 0x41, 0x35, 0x30, 0x33, 0x31, 0x42, 0x44,
    0x32, 0x45, 0x44, 0x45, 0x41, 0x36, 0x0A
};

static PROGMEM prog_uint32_t crc_table[16] = {
    0x00000000, 0x1db71064, 0x3b6e20c8, 0x26d930ac,
    0x76dc4190, 0x6b6b51f4, 0x4db26158, 0x5005713c,
    0xedb88320, 0xf00f9344, 0xd6d6a3e8, 0xcb61b38c,
    0x9b64c2b0, 0x86d3d2d4, 0xa00ae278, 0xbdbdf21c
};

unsigned long crc_update(unsigned long crc, byte data)
{
    byte tbl_idx;
    tbl_idx = crc ^ (data >> (0 * 4));
    crc = pgm_read_dword_near(crc_table + (tbl_idx & 0x0f)) ^ (crc >> 4);
    tbl_idx = crc ^ (data >> (1 * 4));
    crc = pgm_read_dword_near(crc_table + (tbl_idx & 0x0f)) ^ (crc >> 4);
    return crc;
}

void I2CEEPROM_Write( unsigned int address, byte data )
{
  Wire.beginTransmission(eeprom_addr);
  Wire.write((int)highByte(address) );
  Wire.write((int)lowByte(address) );
  Wire.write(data);
  Wire.endTransmission();
  delay(5); // wait for the I2C EEPROM to complete the write cycle
}

byte I2CEEPROM_Read(unsigned int address )
{
  byte data;
  Wire.beginTransmission(eeprom_addr);
  Wire.write((int)highByte(address) );
  Wire.write((int)lowByte(address) );
  Wire.endTransmission(false);
  Wire.requestFrom(eeprom_addr,(byte)1);
  while(Wire.available() == 0) // wait for data
    ;
  data = Wire.read();
  return data;
}
  



void setup()
{
  pinMode(led, OUTPUT);
  Serial.begin (9600);
  
  Wire.begin(); // join i2c bus (address optional for master)
 
  // Write the Data
  int x = 0;
  
  // Write the data out to the EEPROM
  for (x = 0; x < sizeof(eeprom_data); x++)
  {
    I2CEEPROM_Write (x, eeprom_data[x] );
  }

  
  // Calculate a CRC on the original data
  for (x = 0; x < sizeof(eeprom_data); x++)
  {
    crc = crc_update (crc, eeprom_data[x]);
  }
    
  //Delay to see a clean break on a logic analyzer
  delay(10);
  
  //Read back each byte from the EEPROM and calculate a CRC on that
 for (x = 0; x < sizeof(eeprom_data); x++)
 {
   byte b = I2CEEPROM_Read (x);
   crc_check = crc_update (crc_check, b);
 }
  
}



void loop()
{
  // The CRC on the original data should match the crc from the read back data
  if (crc == crc_check)
    {
        digitalWrite(led, HIGH);
        delay(1000);
        digitalWrite(led, LOW);
        delay(1000);
    }
  else
    {
        digitalWrite(led, HIGH);
        delay(200);
        digitalWrite(led, LOW);
        delay(200);
        digitalWrite(led, HIGH);
        delay(200);
        digitalWrite(led, LOW);
        delay(1000);
    }
   
}

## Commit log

2014-01-17 Initial file commit
    [cryptocape.brd, cryptocape.sch]
2014-01-27 Fixes spacing and silk for jumpers
    [cryptocape.brd]
2014-01-30 tightening up footprints, still a work in progress
    [cryptocape.brd]
2014-01-31 Adds ATAES123 and Cryptotronix Logo
    [cryptocape.brd, cryptocape.sch]
2014-02-04 finished layout with lables. Board is in state for review
    [cryptocape.brd, cryptocape.sch]
2014-02-04 Fixed airwire issue
    [cryptocape.brd]
2014-02-04 Added label for I2C EN.
    [cryptocape.brd]
2014-02-04 added authors and version
    [cryptocape.brd]
2014-02-04 added authors on Schematic
    [cryptocape.sch]
2014-02-04 added version on schematic
    [cryptocape.sch]
2014-02-04 added v02
    [cryptocape.brd]
2014-02-04 fixed capacitor C7 alignment to match C11
    [cryptocape.brd]
2014-02-27 Fixed off angle wire and added TP for RTC battery.
    [cryptocape.brd]
2014-03-03 Superficial changes to schematic and board.
    - Fixes bent wire on schematic on BBB header.
    - Changes "set" to "clear" on EEPROM
    - Adds ATATES132 to I2C address list
    - Resorts the list by address
    - Changes "Atmel Trusted Platform Module" to TPM on brd
    - Changes "MEGA328" to "m328P"
    [cryptocape.brd, cryptocape.sch]
2014-03-03 bumped some vias to clear DRC ready for RED
    [cryptocape.brd]
2014-03-04 Changed I2C EN to PU EN
    [cryptocape.brd]
2014-03-04 added fiducials
    regular local fiducials
    [cryptocape.brd, cryptocape.sch]
2014-03-04 created panel v02
    [cryptocape-panel-v02.brd]
2014-03-04 added "route out" for PCB fab house
    [cryptocape-panel-v02.brd]
2014-04-11 Adds example code to burn the EEPROM from the ATmega328p
    [crypto_cape_writer.ino]
2015-12-09 Adding docoumentation with board pdf, updating readme, fixing directory name
    [cryptocape-panel-v02.brd]

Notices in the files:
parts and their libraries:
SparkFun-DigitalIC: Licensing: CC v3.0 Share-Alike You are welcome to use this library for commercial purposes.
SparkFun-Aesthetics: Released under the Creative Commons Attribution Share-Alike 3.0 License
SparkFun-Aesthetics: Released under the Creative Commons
